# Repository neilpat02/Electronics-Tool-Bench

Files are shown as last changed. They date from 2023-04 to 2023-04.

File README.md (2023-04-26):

# Electronics-Tool-Bench
Led a team of 5 engineering students (including myself) in a semester-long project. The Electronics Tool Bench features a Voltmeter, Ohmmeter, Function Generator (Sine and Square Waves), DC Reference, and Frequency Measurements. Served as the Project Manager and Software Lead

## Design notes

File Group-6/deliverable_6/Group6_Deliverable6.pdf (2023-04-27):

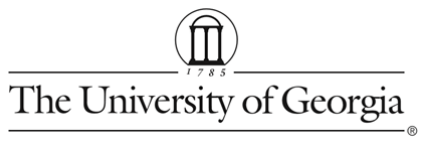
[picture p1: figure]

## ECSE 2920: Design Methodology Deliverable 6 Group 6

02/15/2023

Part 1: Negative Voltage Simulation
Requirements:
- Provide a schematic (digitally drawn in your chosen PCB software) AND a simulation of your design from multisim, LTSpice, Simulink, Altium, etc.
- Need to show a stand-alone circuit working with your +12V DC source coming from a lab power supply.
- Your V+ and V- reference point should be around +/- 6 volts

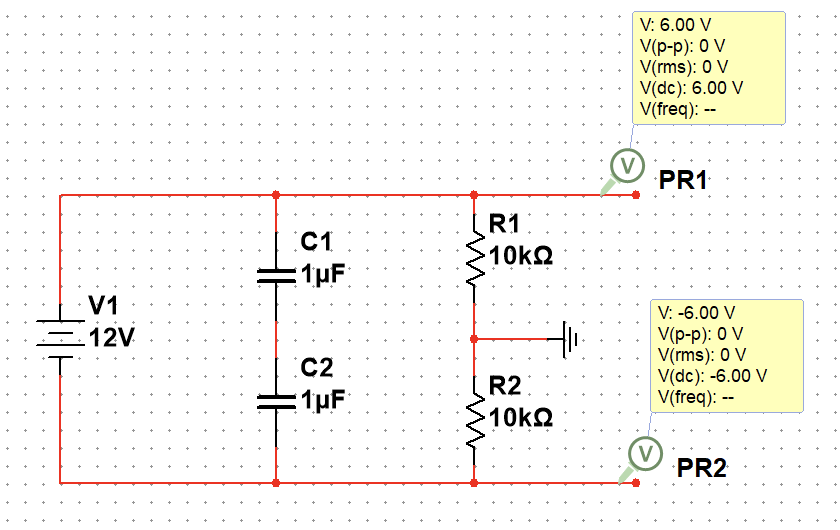
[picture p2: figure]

To start our simulation, we decided to work in Multisim since it was the most user-friendly and each of us on the team have used it before. The picture above demonstrates our idea for a voltage splitter to take the +12V DC supply and creates two new voltage references, each one being +6V and -6V respectively. In the research for this circuit, we’ve found that we can use two capacitors connected together in series in order to store some of the electrical energy. This creates a potential difference between the two terminals of the capacitor. We’ve taken advantage of this potential difference to have a positive and a negative terminal. In order to divide the +12V between our two terminals, our circuit includes a voltage divider using two 10kOhm resistors connected in series with each other. This effectively takes the +12V and splits it into +6V on one terminal and -6V on the other one.

We will include our Multisim simulation file in the submission of this week’s deliverable.

Part 2: ADC
Requirements:
- For this deliverable provide an ADC design of at least 4-bits
- This is a stand-alone design and does not need to be attached to the PI

(For better clarity, the image of our Multisim circuit is on the next page)

The page below contains our 4-bit ADC circuit design. On the far left side of the picture is our “VANALOG” signal. This is meant to be our input analog signal that’s to be converted to a digital signal in our output. We arbitrarily picked a 3V analog signal for testing purposes. In order to convert the signal, we’ve employed the LM339N IC in our circuit. The LM339N is a quad comparator IC that contains four independent voltage comparators in a single package. It has a wide range of applications, including voltage level detection, waveform shaping, pulse and square wave generation, and (in our case) analog-to-digital conversion. An image of the pin layout and a link to the datasheet page will be provided in this deliverable. We’ve taken the +12V DC supply and split it amongst pins 4,6, 8, and 10. For each pin, the voltage of the +12V is divided by 2 for each pin. In other words, the +12V is split into +6V, +3V, and +1.5V for each pin. This can be seen in the schematic as well in the picture on the next page.

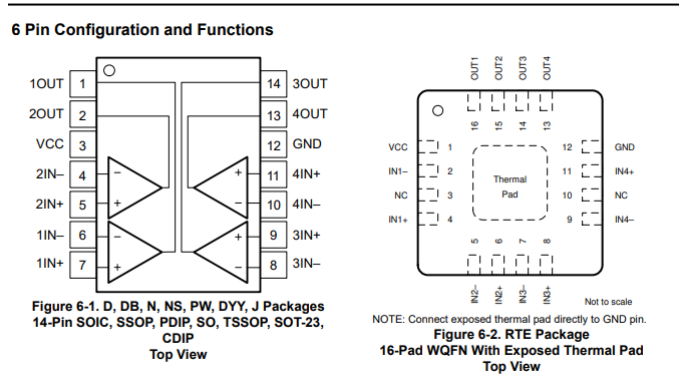
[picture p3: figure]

Datasheet:
https://www.ti.com/lit/ds/symlink/lm339.pdf?HQS=dis-dk-null-digikeymode-dsf-pf-null-wwe&ts=1676389 773462 (https://www.ti.com/lit/ds/symlink/lm339.pdf?HQS=dis-dk-null-digikeymode-dsf-pf-null-wwe&ts=1676389773462)

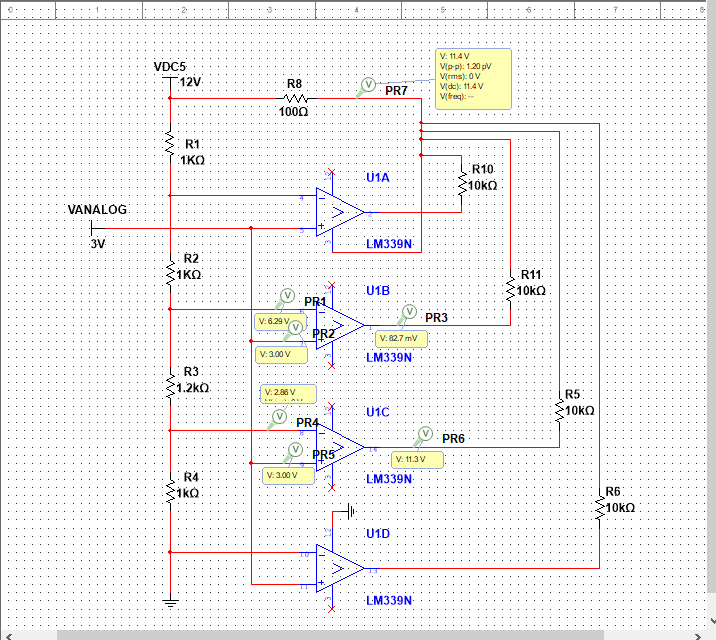
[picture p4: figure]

This is the screenshot of our 4-bit ADC design. Please see the paragraph written on the page above for our explanation of our design and why we chose certain components.

Part 3: Team Design Decisions

With every project and circuit comes several decisions that we have to make as engineers in order to achieve an end goal. For instance, there are countless ways that one could construct an Analog-to-Digital Converter circuit. The most popular ADC that we found is a Successive Approximation (SAR) ADC, which converts an analog signal to a digital signal in a step-by-step manner by using a binary search algorithm to find the digital code that best approximates the input signal. Another one that we found was the Flash ADC, which (as the name suggests) is very fast in performance but is relatively expensive; it uses a bank of comparators to convert an analog signal to a digital code in a single clock cycle.

Another decision that we had to make was deciding which design we wanted to commit to for our voltage splitter circuit. At first we had found a design for a potential circuit which splits the +12V DC into two positive and negative terminals using a half-wave rectifier circuit with a low pass filter to create the negative voltage. We tried playing around with certain diodes and capacitor values, but we could not get the circuit to properly split the two ends evenly into +6V and -6V. In the end, we settled with our current design and we’re pretty content with how it turned out.

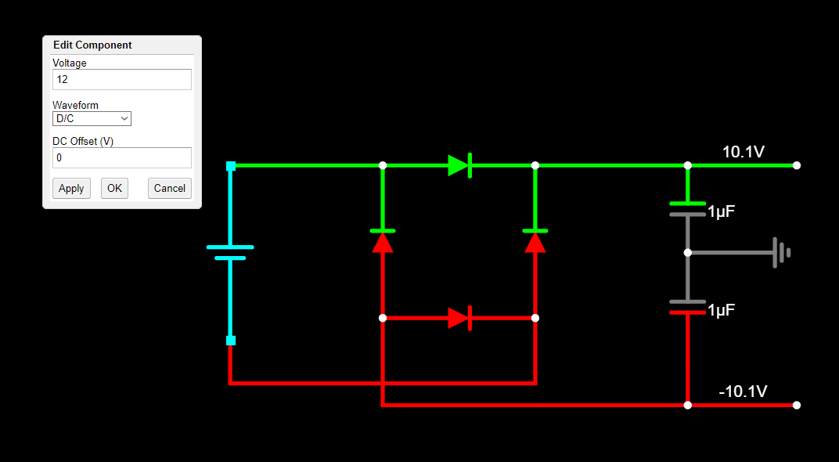
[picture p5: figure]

A prototype of our voltage splitter circuit using a half-wave rectifier. For some reason, the two terminals were split into +10.1V and -10.1V, respectively. Changing the capacitor values for 10uF to 1uF did not change anything.

Conclusion and Participation

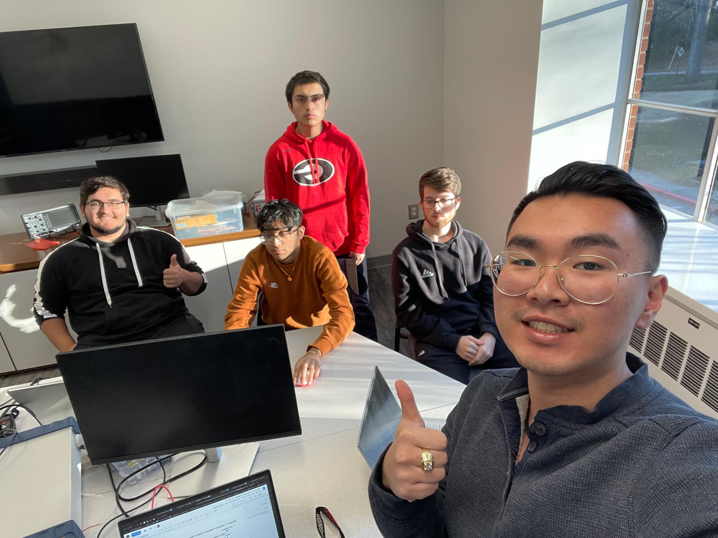
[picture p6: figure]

This picture was taken immediately after class on Monday. After passing Checkpoint C the week before, we came into this week’s deliverable with high spirits. As always, Neil drafted up the plan for this week’s deliverable and we jumped into action. For this week’s deliverable, Daniel and Kevin took the lead in brainstorming ideas for each of our circuit diagrams. We knew that we weren’t required to have a working circuit this week, but that didn’t stop us from trying our best to get something on the table. We played around in Multisim for a while until we found solutions for each of our respective circuits. Once each circuit passed the desired outcome for each scenario that we needed it to do, we switched over to Eagle and used CAD in order to sketch up a proper diagram. For this week’s deliverable, we will be submitting 5 files: One Multisim file for our ADC, one Eagle file for our ADC schematic, one Multisim file for our voltage splitter, one Eagle file for our voltage splitter schematic, and this week’s deliverable write up.

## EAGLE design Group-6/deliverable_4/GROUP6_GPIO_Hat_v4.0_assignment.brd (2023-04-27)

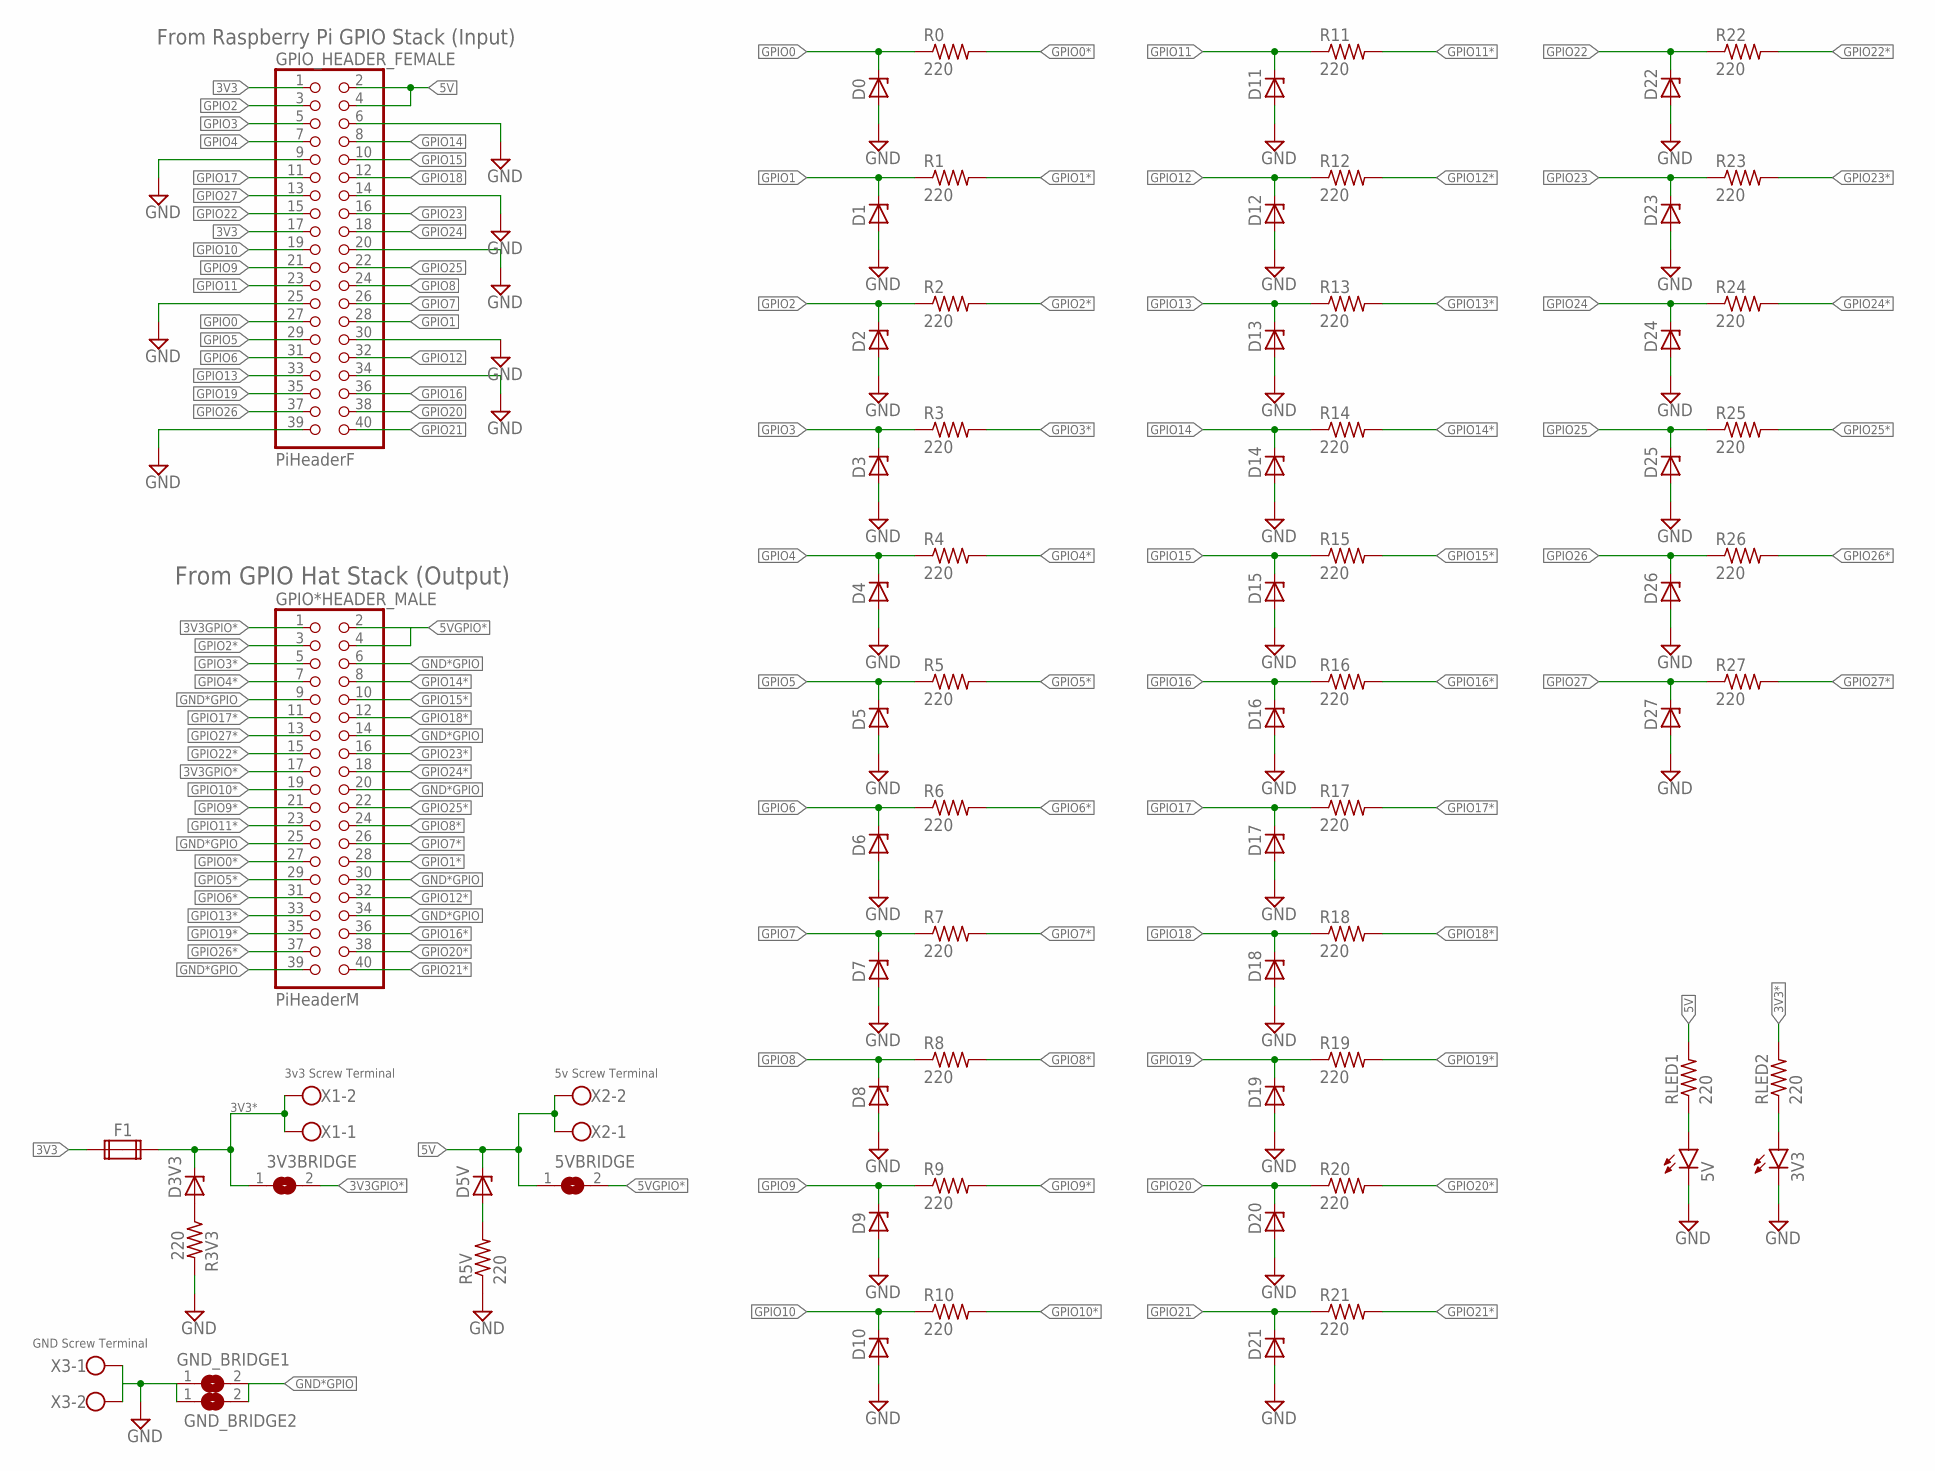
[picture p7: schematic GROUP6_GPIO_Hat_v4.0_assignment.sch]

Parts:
3V3, 5V: LED5MM
3V3BRIDGE, 5VBRIDGE: SJ
D0, D1, D2, D3, D3V3, D4, D5, D5V, D6, D7, D8, D9, D10, D11, D12, D13, D14, D15, D16, D17, D18, D19, D20, D21, D22, D23, D24, D25, D26, D27: 1N4728; DO41Z10
F1: FUSE2P; FUSE1
GND_BRIDGE1, GND_BRIDGE2: SJ
GPIO*HEADER_MALE: PiHeaderM; 2X20
GPIO_HEADER_FEMALE: PiHeaderF; 2X20
R0, R1, R2, R3, R3V3, R4, R5, R5V, R6, R7, R8, R9, R10, R11, R12, R13, R14, R15, R16, R17, R18, R19, R20, R21, R22, R23, R24, R25, R26, R27: 220; 0207/10
RLED1, RLED2: 220; 0207/10
X1, X2, X3: W237-102

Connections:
3V3: F1.1A, GPIO_HEADER_FEMALE.1, GPIO_HEADER_FEMALE.17
3V3*: 3V3BRIDGE.1, D3V3.C, F1.2A, RLED2.2, X1.1, X1.2
3V3GPIO*: 3V3BRIDGE.2, GPIO*HEADER_MALE.1, GPIO*HEADER_MALE.17
5V: 5VBRIDGE.1, D5V.C, GPIO_HEADER_FEMALE.2, GPIO_HEADER_FEMALE.4, RLED1.2, X2.1, X2.2
5VGPIO*: 5VBRIDGE.2, GPIO*HEADER_MALE.2, GPIO*HEADER_MALE.4
GND: 3V3.K (C), 5V.K (C), D0.A, D1.A, D2.A, D3.A, D4.A, D5.A, D6.A, D7.A, D8.A, D9.A, D10.A, D11.A, D12.A, D13.A, D14.A, D15.A, D16.A, D17.A, D18.A, D19.A, D20.A, D21.A, D22.A, D23.A, D24.A, D25.A, D26.A, D27.A, GND_BRIDGE1.1, GND_BRIDGE2.1, GPIO_HEADER_FEMALE.6, GPIO_HEADER_FEMALE.9, GPIO_HEADER_FEMALE.14, GPIO_HEADER_FEMALE.20, GPIO_HEADER_FEMALE.25, GPIO_HEADER_FEMALE.30, GPIO_HEADER_FEMALE.34, GPIO_HEADER_FEMALE.39, R3V3.2, R5V.1, X3.1, X3.2
GND*GPIO: GND_BRIDGE1.2, GND_BRIDGE2.2, GPIO*HEADER_MALE.6, GPIO*HEADER_MALE.9, GPIO*HEADER_MALE.14, GPIO*HEADER_MALE.20, GPIO*HEADER_MALE.25, GPIO*HEADER_MALE.30, GPIO*HEADER_MALE.34, GPIO*HEADER_MALE.39
GPIO0: D0.C, GPIO_HEADER_FEMALE.27, R0.1
GPIO0*: GPIO*HEADER_MALE.27, R0.2
GPIO1: D1.C, GPIO_HEADER_FEMALE.28, R1.1
GPIO1*: GPIO*HEADER_MALE.28, R1.2
GPIO2: D2.C, GPIO_HEADER_FEMALE.3, R2.1
GPIO2*: GPIO*HEADER_MALE.3, R2.2
GPIO3: D3.C, GPIO_HEADER_FEMALE.5, R3.1
GPIO3*: GPIO*HEADER_MALE.5, R3.2
GPIO4: D4.C, GPIO_HEADER_FEMALE.7, R4.1
GPIO4*: GPIO*HEADER_MALE.7, R4.2
GPIO5: D5.C, GPIO_HEADER_FEMALE.29, R5.1
GPIO5*: GPIO*HEADER_MALE.29, R5.2
GPIO6: D6.C, GPIO_HEADER_FEMALE.31, R6.1
GPIO6*: GPIO*HEADER_MALE.31, R6.2
GPIO7: D7.C, GPIO_HEADER_FEMALE.26, R7.1
GPIO7*: GPIO*HEADER_MALE.26, R7.2
GPIO8: D8.C, GPIO_HEADER_FEMALE.24, R8.1
GPIO8*: GPIO*HEADER_MALE.24, R8.2
GPIO9: D9.C, GPIO_HEADER_FEMALE.21, R9.1
GPIO9*: GPIO*HEADER_MALE.21, R9.2
GPIO10: D10.C, GPIO_HEADER_FEMALE.19, R10.1
GPIO10*: GPIO*HEADER_MALE.19, R10.2
GPIO11: D11.C, GPIO_HEADER_FEMALE.23, R11.1
GPIO11*: GPIO*HEADER_MALE.23, R11.2
GPIO12: D12.C, GPIO_HEADER_FEMALE.32, R12.1
GPIO12*: GPIO*HEADER_MALE.32, R12.2
GPIO13: D13.C, GPIO_HEADER_FEMALE.33, R13.1
GPIO13*: GPIO*HEADER_MALE.33, R13.2
GPIO14: D14.C, GPIO_HEADER_FEMALE.8, R14.1
GPIO14*: GPIO*HEADER_MALE.8, R14.2
GPIO15: D15.C, GPIO_HEADER_FEMALE.10, R15.1
GPIO15*: GPIO*HEADER_MALE.10, R15.2
GPIO16: D16.C, GPIO_HEADER_FEMALE.36, R16.1
GPIO16*: GPIO*HEADER_MALE.36, R16.2
GPIO17: D17.C, GPIO_HEADER_FEMALE.11, R17.1
GPIO17*: GPIO*HEADER_MALE.11, R17.2
GPIO18: D18.C, GPIO_HEADER_FEMALE.12, R18.1
GPIO18*: GPIO*HEADER_MALE.12, R18.2
GPIO19: D19.C, GPIO_HEADER_FEMALE.35, R19.1
GPIO19*: GPIO*HEADER_MALE.35, R19.2
GPIO20: D20.C, GPIO_HEADER_FEMALE.38, R20.1
GPIO20*: GPIO*HEADER_MALE.38, R20.2
GPIO21: D21.C, GPIO_HEADER_FEMALE.40, R21.1
GPIO21*: GPIO*HEADER_MALE.40, R21.2
GPIO22: D22.C, GPIO_HEADER_FEMALE.15, R22.1
GPIO22*: GPIO*HEADER_MALE.15, R22.2
GPIO23: D23.C, GPIO_HEADER_FEMALE.16, R23.1
GPIO23*: GPIO*HEADER_MALE.16, R23.2
GPIO24: D24.C, GPIO_HEADER_FEMALE.18, R24.1
GPIO24*: GPIO*HEADER_MALE.18, R24.2
GPIO25: D25.C, GPIO_HEADER_FEMALE.22, R25.1
GPIO25*: GPIO*HEADER_MALE.22, R25.2
GPIO26: D26.C, GPIO_HEADER_FEMALE.37, R26.1
GPIO26*: GPIO*HEADER_MALE.37, R26.2
GPIO27: D27.C, GPIO_HEADER_FEMALE.13, R27.1
GPIO27*: GPIO*HEADER_MALE.13, R27.2
unnamed: 5V.A, RLED1.1
unnamed: D3V3.A, R3V3.1
unnamed: D5V.A, R5V.2
unnamed: 3V3.A, RLED2.1

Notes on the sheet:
From Raspberry Pi GPIO Stack (Input)
GND Screw Terminal
5v Screw Terminal
3v3 Screw Terminal
From GPIO Hat Stack (Output)

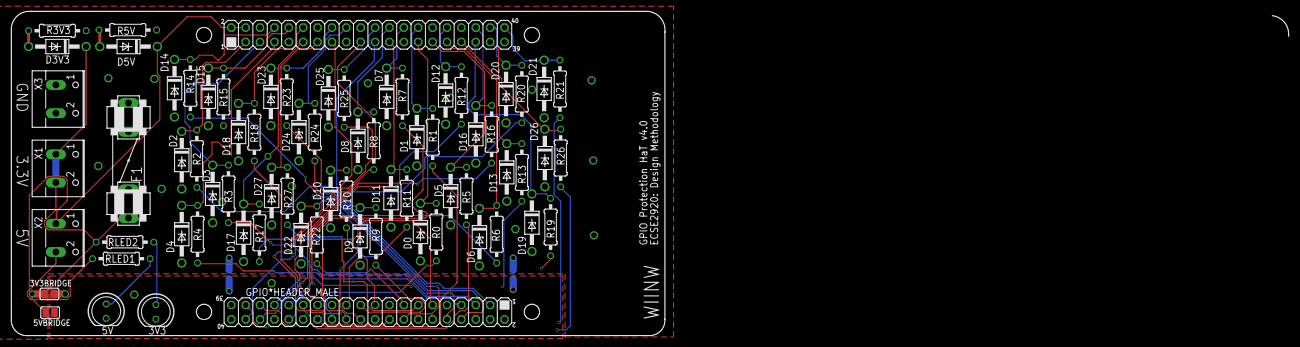
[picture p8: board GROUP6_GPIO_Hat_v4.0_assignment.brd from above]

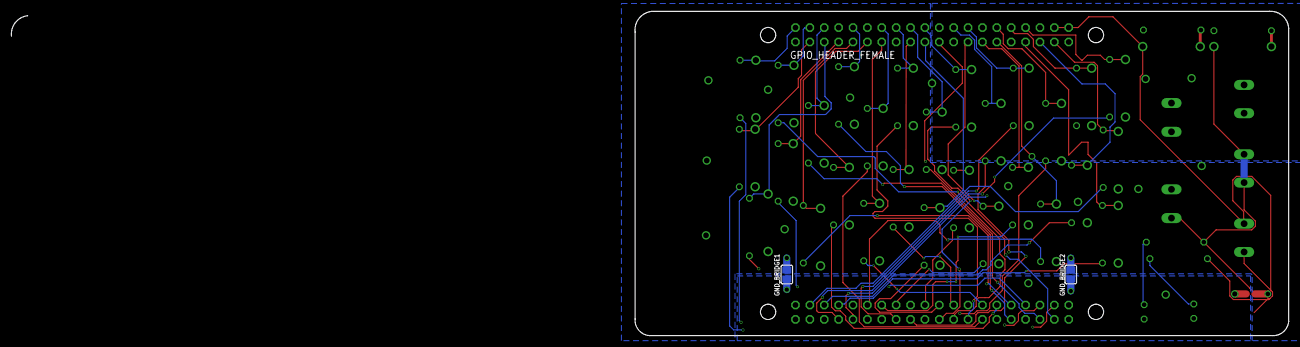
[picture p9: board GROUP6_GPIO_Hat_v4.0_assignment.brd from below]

Board: 4 copper layers, 115.5 x 57.3 mm, 74 parts (2 on the bottom side), 67 nets.

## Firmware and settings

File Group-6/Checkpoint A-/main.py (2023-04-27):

import RPi.GPIO as GPIO
import time
import rgb1602
import spidev
import pigpio
import random
import math
# Set up the pins
compOut = 5
comp = 6
compInt = 14
clk = 17
dt = 18
btn = 27
# Set up the PWM pin
PWM_PIN = 12
#initialize pigpio
pi = pigpio.pi()
cs = 7
pi.set_mode(cs, pigpio.OUTPUT)
readFreq = 0
# Set up the RGB1602 display
lcd = rgb1602.RGB1602(16,2)
lcd.setRGB(0,128,128) # Set the RGB color to teal
#setting up the rotary encoder and comparator output pin
GPIO.setmode(GPIO.BCM)
GPIO.setup(comp, GPIO.IN, pull_up_down=GPIO.PUD_DOWN)
GPIO.setup(compOut, GPIO.IN, pull_up_down=GPIO.PUD_DOWN)
GPIO.setup(clk, GPIO.IN, pull_up_down=GPIO.PUD_UP)
GPIO.setup(dt, GPIO.IN, pull_up_down=GPIO.PUD_UP)
GPIO.setup(btn, GPIO.IN, pull_up_down=GPIO.PUD_UP)
GPIO.setup(compInt, GPIO.IN, pull_up_down=GPIO.PUD_UP)
GPIO.setup(16, GPIO.IN)
# Set up the RGB1602 display
lcd = rgb1602.RGB1602(16, 2)
lcd.setRGB(0,128,128)
# Set up the SPI interface
spi = spidev.SpiDev()
spi.open(0, 0)
spi.mode = 0
spi.max_speed_hz = 1000000
spi.xfer2([0x10, 128])
spi2 = spidev.SpiDev()
spi2.open(0,1)
spi2.mode = 0
spi2.max_speed_hz = 1000000
spi2.xfer2([0x00,128])
voltVal = 0
#for the function generator, gave it a default value of 100 Hz
currentFreq = 100
currentFreq2 = 1000
desiredFreq = currentFreq
desiredFreq2 = currentFreq2
Amp = 2.5
#keep track of the last time the rotary encoder was rotated
last_rotation_time = time.time()

"""
The ohmmeter function will use the comparator output to determine the resistance of the unknown resistor.
We have characterized our digital potentiometer to have a resistance of 72 ohms per step. The initial resistance
of the potentiometer is 111 ohms. The comparator output will be high when the resistance of the unknown resistor
is greater than the resistance of the potentiometer. The comparator output will be low when the resistance of the
unknown resistor is less than the resistance of the potentiometer. The digital potentiometer will be adjusted
until the comparator output is low. The digital potentiometer will be adjusted by 1 step at a time. The resistance
of the unknown resistor will be calculated by multiplying the number of steps the potentiometer was adjusted by
72 ohms. The resistance of the unknown resistor will be displayed on the LCD screen.
"""
def ohmmeter():
    print("inside res val")
    global R_unknown
    val = True
    wiper_pos = 128
    spi.xfer2([0x10, wiper_pos])
    while GPIO.input(compOut) == 0:
        print(GPIO.input(compOut))
        time.sleep(0.01)
        spi.xfer2([0x10, wiper_pos])
        wiper_pos -= 1
        print("inside while loop: ", wiper_pos)
        if wiper_pos <= 0:
            break
    if wiper_pos == 128: 
        R_unknown = 111 
    elif wiper_pos == 127:
        R_unknown = 183
    elif wiper_pos <= 0:
        R_unknown = 9288
    else:
        wiper_pos2 = 128 - wiper_pos
        R_unknown = ((wiper_pos2 + 1) * 73)
    print(GPIO.input(compOut))     
    lcd.setCursor(0, 1)
    lcd.printout(str(R_unknown) + " Ohms")
    
"""
The two functions below are used for the function generator. The set_frequency function will set the frequency of the
square wave. The square_wave function will set the frequency of the square wave and turn the output on or off.
pigpio is used to set the frequency of the square wave.
"""
def set_frequency(pin, freq): 
    pi.set_mode(pin, pigpio.OUTPUT)
    frequency = int(freq)
    pi.hardware_PWM(pin, freq, 500000)
    print(pin)
    print("Frequency set to {} Hz".format(frequency)) #This is used for testing

def square_wave(freq, output_on):
    global getFreq
    #getFreq = currentFreq
    getFreq = desiredFreq
    print(f"Setting square wave frequency to {getFreq} Hz") #This is used for testing
    
    if output_on: #this if-statement will be invoked if the flag is set to True, indicating that the output should be on.
        set_frequency(PWM_PIN, getFreq)
    else: #this else-statement will be invoked if the flag is set to False, indicating that the output should be off, when the user presses the 'off', 'back', or 'main' button.
        set_frequency(PWM_PIN, 0)


"""
The following function is the adc function. The adc function will use the comparator output to determine the voltage
of the unknown voltage source. The digital potentiometer will be adjusted until the comparator output is low. The
digital potentiometer will be adjusted by 1 step at a time. The voltage of the unknown voltage source will be calculated
by multiplying the number of steps the potentiometer was adjusted by 0.25 volts. The voltage of the unknown voltage
source will be displayed on the LCD screen.
"""
def adc(arg = None):
    if arg == None: #if arg is None, then the function is able to take the measure the external voltage source.
        #set 2v
        spi.xfer2([0x00, 113])
        if GPIO.input(comp) == 0:  # Greater than 2V
            #set 3v
            spi.xfer2([0x00, 91])
            if GPIO.input(comp) == 0:  # Greater than 3V
                # Set 3.5V
                spi.xfer2([0x00, 72])
                if GPIO.input(comp) == 0:  # Greater than 3.5V
                    # Set 3.75V
                    spi.xfer2([0x00, 50])
                    if GPIO.input(comp) == 0:  # Greater than 3.75V
                        return 3.75
                    else:  # Less than 3.75V
                        return 3.5
                else:  # Less than 3.5V
                    # Set 3.25V
                    spi.xfer2([0x00, 83])
                    if GPIO.input(comp) == 0:  # Greater than 3.25V
                        return 3.25
                    else:  # Less than 3.25V
                        return 3
            else:  # Less than 3V
                # Set 2.5V
                spi.xfer2([0x00, 104])
                if GPIO.input(comp) == 0:  # Greater than 2.5V
                    # Set 2.75V
                    spi.xfer2([0x00, 98])
                    if GPIO.input(comp) == 0:  # Greater than 2.75V
                        return 2.75
                    else:  # Less than 2.75V
                        return 2.5
                else:  # Less than 2.5V
                    # Set 2.25V
                    spi.xfer2([0x00, 108])
                    if GPIO.input(comp) == 0:  # Greater than 2.25V
                        return 2.25
                    else:  # Less than 2.25V
                        return 2
        else:  # Less than 2V
            # Set 1V
            spi.xfer2([0x00, 123])
            if GPIO.input(comp) == 0:  # Greater than 1V
                # Set 1.5V
                spi.xfer2([0x00, 119])
                if GPIO.input(comp) == 0:  # Greater than 1.5V
                    # Set 1.75V
                    spi.xfer2([0x00, 116])
                    if GPIO.input(comp) == 0:  # Greater than 1.75V
                        return 1.75
                    else:  # Less than 1.75V
                        return 1.5
                else:  # Less than 1.5V
                    # Set 1.25V
                    spi.xfer2([0x00, 121])
                    if GPIO.input(comp) == 0:  # Greater than 1.25V
                        return 1.25
                    else:  # Less than 1.25V
                        return 1
            else:  # Less than 1V
                # Set 0.5V
                spi.xfer2([0x00, 127])
                if GPIO.input(comp) == 0:  # Greater than 0.5V
                    # Set 0.75V
                    spi.xfer2([0x00, 125])
                    if GPIO.input(comp) == 0:  # Greater than 0.75V
                        return 0.75
                    else:  # Less than 0.75V
                        return 0.5
                else:  # Less than 0.5V
                    # Set 0.25V
                    spi.xfer2([0x00, 128])
                    if GPIO.input(comp) == 0:  # Greater than 0.25V
                        return 0.25
                    else:  # Less than 0.25V
                        return 0
    elif arg != None: #if the arg is not None, then the function will be able to set the digital potentiometer to a specific voltage, based on the internal voltage input.
        if arg == 0.25: #set to 0.25V
            spi.xfer2([0x00, 128])
        elif arg == 0.50: #set to 0.50V
            spi.xfer2([0x00, 127])
        elif arg == 0.75: #set to 0.75V
            spi.xfer2([0x00, 125])
        elif arg == 1.00: #set to 1.00V
            spi.xfer2([0x00, 123])
        elif arg == 1.25:  # set to 1.25V
            spi.xfer2([0x00, 121])
        elif arg == 1.50:  # set to 1.50V
            spi.xfer2([0x00, 119])
        elif arg == 1.75: # set to 1.75V
            spi.xfer2([0x00, 116])
        elif arg == 2.00: #set to 2.00V
            spi.xfer2([0x00, 113])
        elif arg == 2.25: #set to 2.25V
            spi.xfer2([0x00, 108])
        elif arg == 2.50: #set to 2.50V
            spi.xfer2([0x00, 104])
        elif arg == 2.75: #set to 2.75V
            spi.xfer2([0x00, 98])
        elif arg == 3.00: #set to 3.00V
            spi.xfer2([0x00, 91])
        elif arg == 3.25: #set to 3.25V
            spi.xfer2([0x00, 83])
        elif arg == 3.50: #set to 3.50V
            spi.xfer2([0x00, 72])
        elif arg == 3.75: #set to 3.75V
            spi.xfer2([0x00, 50])
        elif arg > 3.75: #if the voltage is greater than 3.75V, then the function will set the digital potentiometer to 3.75V, which is the maximum voltage that the digital potentiometer can handle.
            spi.xfer2([0x00,50])

#simple function to call the adc function and return the voltage which will be displayed on the LCD screen. 
def voltmeter():
    voltage = adc()
    return voltage

"""
the internal_ref function is used to set the digital potentiometer to a specific voltage, based on the internal voltage input.
the digitpot was characterized by testing the voltage output at each step of the digital potentiometer. Based on the voltage output, 
the digital potentiometer was set to the closest voltage to the internal voltage input.
"""
def internal_ref(val):
    global voltVal
    voltVal = val
    if voltVal == 0.25:
        spi2.xfer2([0x00, 128])
    elif voltVal == 0.50:
        spi2.xfer2([0x00,127])
    elif voltVal == 0.75:
        spi2.xfer2([0x00,125])
    elif voltVal == 1.00:
        spi2.xfer2([0x00,123])
    elif voltVal == 1.25:
        spi2.xfer2([0x00,121])
    elif voltVal == 1.50:
        spi2.xfer2([0x00,119])
    elif voltVal == 1.75:
        spi2.xfer2([0x00,116])
    elif voltVal == 2.00:
        spi2.xfer2([0x00,113])
    elif voltVal == 2.25:
        spi2.xfer2([0x00,109])
    elif voltVal == 2.50:
        spi2.xfer2([0x00,104])
    elif voltVal == 2.75:
        spi2.xfer2([0x00,98])
    elif voltVal == 3.00:
        spi2.xfer2([0x00,92])
    elif voltVal == 3.25:
        spi2.xfer2([0x00,84])
    elif voltVal == 3.50:
        spi2.xfer2([0x00,73])
    elif voltVal == 3.75:
        spi2.xfer2([0x00,56])
    elif voltVal == 4.00:
        spi2.xfer2([0x00,25])
    adc(voltVal)
    
# Initialize the counter. This will be incremented by the pulse function

elapsed_time = 0
freq = 0
pulse = 0

"""This function will be called each time a pulse is received on GPIO 16 due to a falling edge case
   Over a specific time interval and be used to determine the frequency of the signal.The periodic signal’s 
   frequency can be described as the number of cycles it completed in one second. The code counts the number of 
   rising edge cases through the connected GPIO pin that reads the comparator's output. A rising edge is the transition from a 
   low voltage level to high voltage level. Each time a rising edge case is detected the pulse function is called and has a counter 
   to keep track of the number of times. The program waits for a predefined time interval (2.5 seconds in this case) while counting 
   the pulses
"""

def pulseCounter(gpio, level, tick):
    global pulse
    pulse = pulse + 1

def external():
    global elapsed_time 
    global pulse
    global current_menu 
    global readFreq
    if(pi.read(btn) == 0): #if the button is pressed, then the program will read the frequency of the signal
        begin = time.time()
        pulseCount = pi.callback(16, pigpio.FALLING_EDGE, pulseCounter)
        time.sleep(2.5)
        pulseCount.cancel()
        end = time.time()
        elapsed_time = end - begin 
        #Calculate the frequency
        readFreq = math.ceil((1/elapsed_time) * pulse)
        lcd.clear()
        global externalFreqOptions
        externalFreqOptions[0] = f"Frequency: {int(readFreq)} Hz"
        current_menu = externalFreqOptions

    begin = 0
    end = 0
    elapsed_time = 0
    pulse = 0
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

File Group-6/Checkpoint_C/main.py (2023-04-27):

import RPi.GPIO as GPIO
import time
import rgb1602
import subprocess


# Set up the rotary encoder pin numbers
clk = 17
dt = 18
btn = 27

# Set up the RGB1602 display
lcd = rgb1602.RGB1602(16,2)
lcd.setRGB(0,128,128)

GPIO.setmode(GPIO.BCM)
GPIO.setup(clk, GPIO.IN, pull_up_down=GPIO.PUD_UP)
GPIO.setup(dt, GPIO.IN, pull_up_down=GPIO.PUD_UP)
GPIO.setup(btn, GPIO.IN, pull_up_down=GPIO.PUD_UP)

clkLastState = GPIO.input(clk)
currentSelection = 0
selectionOptions = ["OFF","Function Generator", "Ohmmeter", "Voltmeter", "DC Reference", "Back", "Main"]
modeOptions = ["Type", "Frequency", "Amplitude", "Output"]
fgOptions = ["Amplitude", "Type", "Frequency"]
fgTypeOptions = ["Square", "Back", "Main"]
fgFreqOptions = ["Input Frequency", "Back", "Main"]
fgAmpOptions = ["Input Amplitude", "Back", "Main"]
outputOptions = ["On", "Off", "Back", "Main"]
vmSrcOptions = ["External", "Internal Reference", "Back", "Main"]
dcOutputOptions = ["On", "Off", "Back", "Main"]

# Define the rotary encoder callback function
def rotaryCallback(channel):
    global currentSelection, selectionOptions, lcd
    
    # Read the state of the rotary encoder
    clkState = GPIO.input(clk)
    dtState = GPIO.input(dt)

    if clkState != dtState:
        # Clockwise rotation
        currentSelection = (currentSelection + 1) % len(selectionOptions)
    else:
        # Counterclockwise rotation
        currentSelection = (currentSelection - 1) % len(selectionOptions)

    lcd.setCursor(0, 1)
    lcd.printout(selectionOptions[currentSelection])

# Register the rotary encoder callback function for both rising and falling edge
GPIO.add_event_detect(clk, GPIO.BOTH, callback=rotaryCallback, bouncetime=10)

while True:
    # Read the state of the rotary encoder
    clkState = GPIO.input(clk)
    dtState = GPIO.input(dt)

    # If the rotary encoder has been turned, update the current selection
    if clkState != clkLastState:
        if dtState != clkState:
            currentSelection = (currentSelection + 1) % len(selectionOptions)
        else:
            currentSelection = (currentSelection - 1) % len(selectionOptions)

        # Update the second line of the LCD screen
        lcd.setCursor(0,1)
        lcd.clear()
        lcd.printout(selectionOptions[currentSelection])
        

    # Read the state of the rotary encoder switch
    swState = GPIO.input(btn)

    # If the switch is pressed, take action based on the current selection
    if swState == False:
        if selectionOptions[currentSelection] == "OFF":
            lcd.clear()
            GPIO.cleanup()
            exit()
        elif selectionOptions[currentSelection] == "Back":
            # Go back to the main screen
            currentSelection = 0
            lcd.clear()
        elif selectionOptions[currentSelection] == "Function Generator":
            # Handle function generator option
            #...

            currentOptions = fgOptions
            while True:
                lcd.setCursor(0, 1)
                lcd.printout(currentOptions[currentSelection])

                # Read the state of the rotary encoder
                clkState = GPIO.input(clk)
                dtState = GPIO.input(dt)

                # If the rotary encoder has been turned, update the current selection
                if clkState != clkLastState:
                    if dtState != clkState:
                        
                        currentSelection = (currentSelection + 1) % len(currentOptions)
                    else:
                        
                        currentSelection = (currentSelection - 1) % len(currentOptions)

                # Read the state of the rotary encoder switch
                swState = GPIO.input(btn)
                

                # If the switch is pressed, take action based on the current selection
                if swState == False:
                    if currentOptions[currentSelection] == "Back":
                        currentSelection = 0
                        break

                # Print "Select Option:" on the first line
                lcd.setCursor(0, 0)
                #lcd.printout("Select Option:")

                # Delay to avoid bouncing of the rotary encoder switch
                time.sleep(0.01)

               # Save the last state of the rotary encoder for comparison next time around
                clkLastState = clkState
   
        elif selectionOptions[currentSelection] == "Ohmmeter":
            # Handle ohmmeter option
            # ...
            lcd.printout("Ohmmeter")
            pass
        elif selectionOptions[currentSelection] == "Voltmeter":
            # Handle voltmeter option
            # ...
            lcd.printout("Inside Voltmeter")
        elif selectionOptions[currentSelection] == "DC Reference":
            # Handle DC reference option
            # ...
            lcd.printout("Inside DC REF")
            pass
        elif selectionOptions[currentSelection] == "Main":
            # Go back to the main screen
            currentSelection = 0
            lcd.clear()

    # Print "Select Mode:" on the first line only once
    if currentSelection == 0:
        lcd.setCursor(0, 0)
        lcd.printout("Select Mode:")

    # Delay to avoid bouncing of the rotary encoder switch
    time.sleep(0.01)

    # Save the last state of the rotary encoder for comparison next time around
    clkLastState = clkState
